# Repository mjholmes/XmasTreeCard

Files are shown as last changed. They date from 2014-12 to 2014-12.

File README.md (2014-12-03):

# XmasTreeCard
#### A geeky Christmas card with LEDs and an OLED display

This circuit and board assembled into a Christmas tree shaped card with 11 LEDs driven by a 12-bit shift register and a small, 0.91", OLED display.

It's a bit rough and needs some more polish when time allows.

This work is licensed under a [Creative Commons Attribution-ShareAlike 4.0 International License](http://creativecommons.org/licenses/by-sa/4.0/).

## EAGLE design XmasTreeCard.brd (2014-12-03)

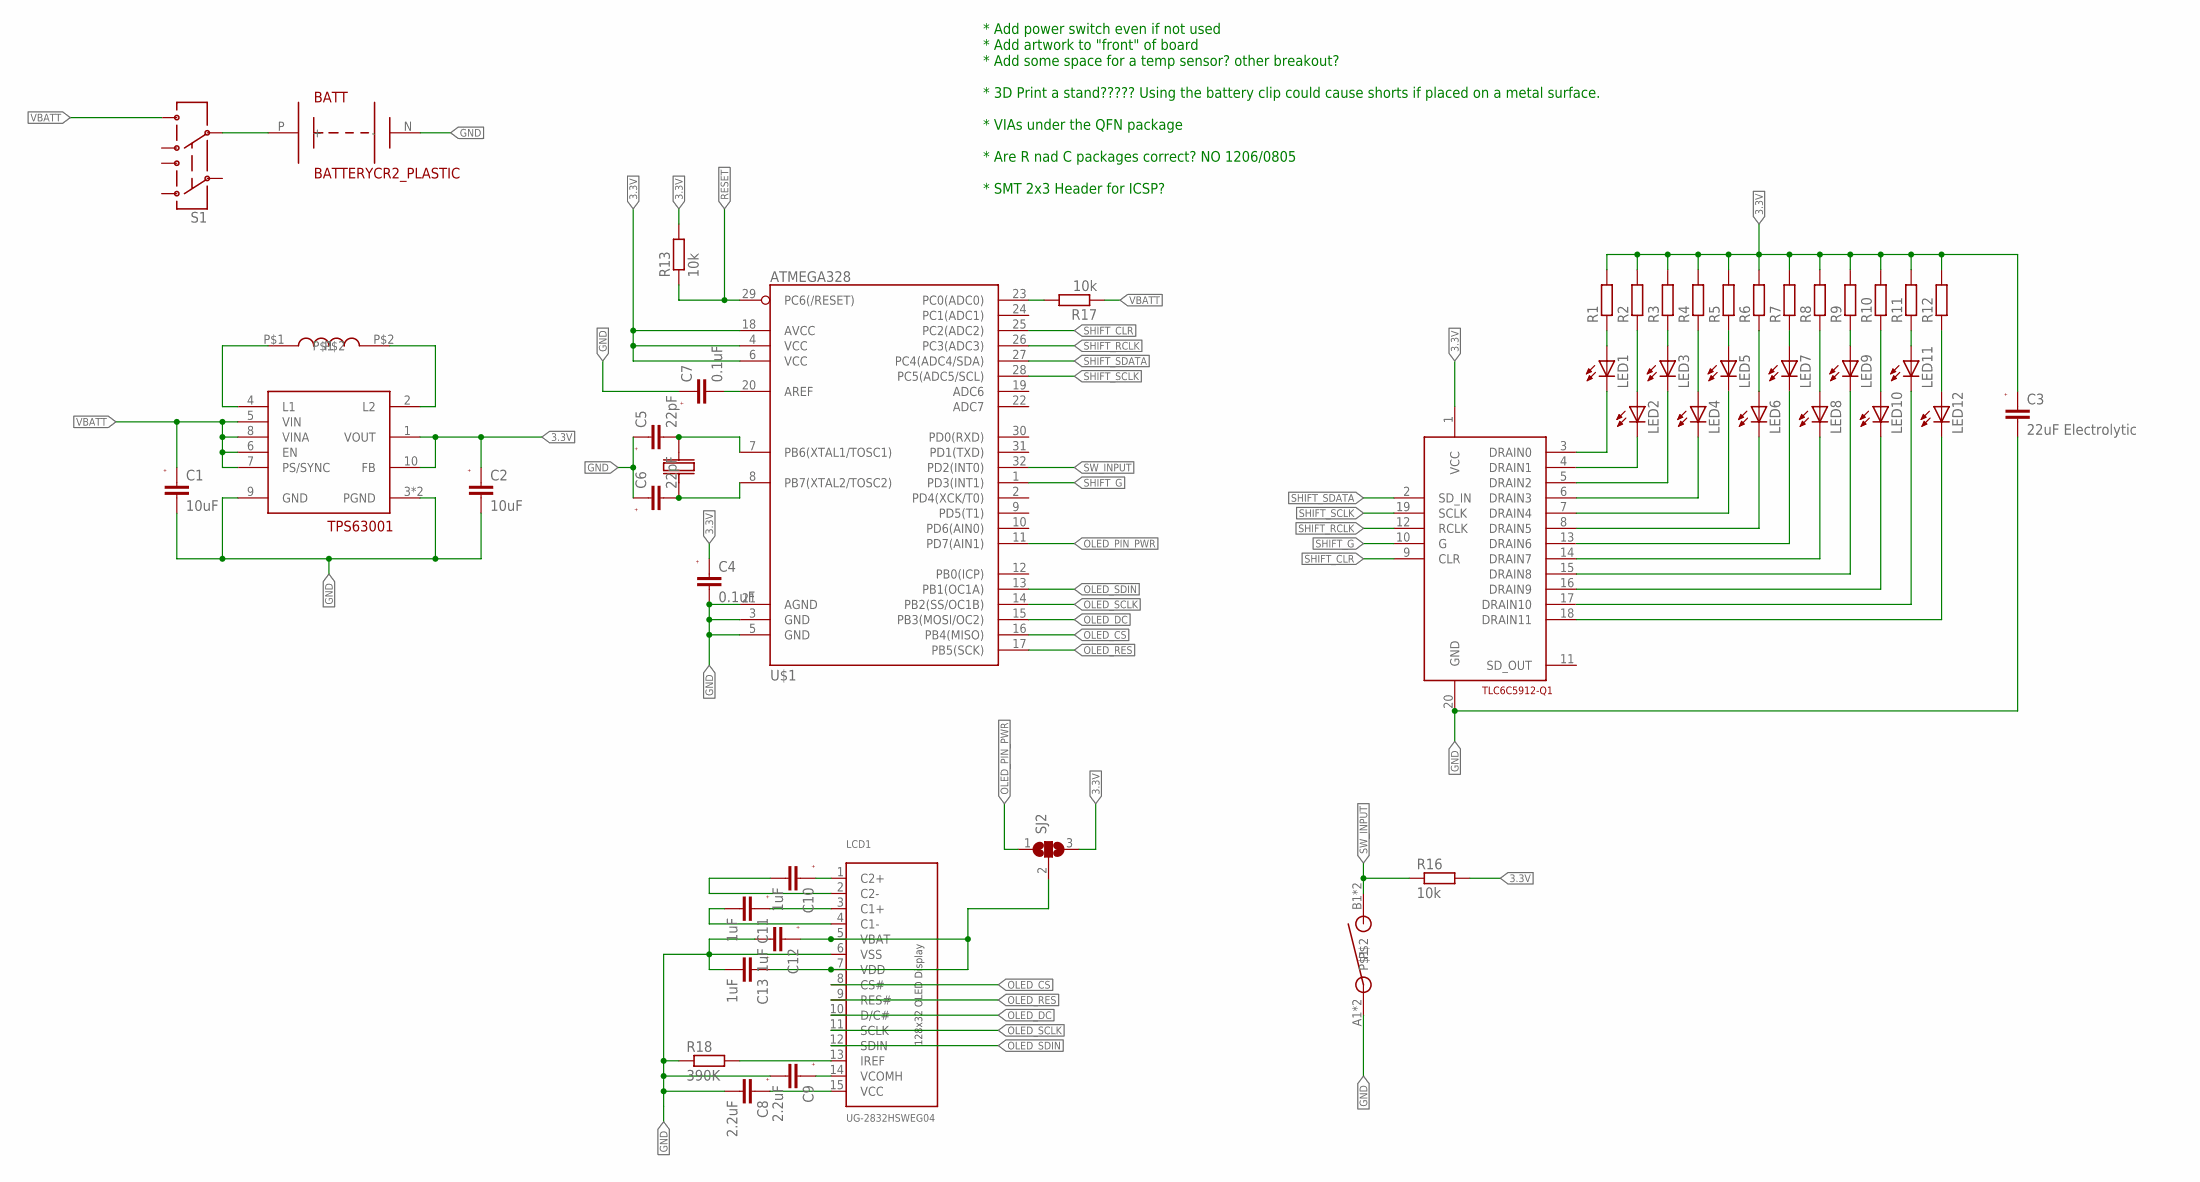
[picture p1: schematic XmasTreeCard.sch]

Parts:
BATT: BATTERYCR2_PLASTIC; BATT_SMD_CR2_PLASTIC
C1, C2: 10uF; C1206
C3: 22uF Electrolytic; CAP_2012-15
C4, C7: 0.1uF; C0805K
C5, C6: 22pF; C0805K
C8, C9: 2.2uF; C1206
C10, C11, C12, C13: 1uF; C1206
LCD1: UG-2832HSWEG04; UG-283HSWEG04_FOLDAROUND
LED1, LED2, LED3, LED4, LED5, LED6, LED7, LED8, LED9, LED10, LED11, LED12: LEDCHIPLED_0805; CHIPLED_0805
R1, R2, R3, R4, R5, R6, R7, R8, R9, R10, R11, R12: R-EUR0805; R0805
R13, R16, R17: 10k; R0805
R18: 390K; R0805
S1: SWITCH-DPDTMMS228; MMS_228_T
SJ2: SJ2W; SJ_2
SW1: SWITCH_SPST6X6TACTILE; SWITCH_SPST_6X6_TACTILE
U$1: ATMEGA328; TQFP32-08
U$2: COILCRAFT_LPS4012
U$3: TPS63001DRC; QFN10_3X3MM
U$4: TLC6C5912-Q1; TSSOP-20
U$5: CRYSTAL_ABM03; ABM_CRYSTAL

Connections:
3.3V: C2.1, C3.P (1), C4.1, R1.2, R2.2, R3.2, R4.2, R5.2, R6.2, R7.2, R8.2, R9.2, R10.2, R11.2, R12.2, R13.2, R16.2, SJ2.3, U$1.4 (VCC), U$1.6 (VCC), U$1.18 (AVCC), U$3.1 (VOUT), U$3.10 (FB), U$4.1 (VCC)
GND: BATT.N (-), C1.2, C2.2, C3.N (2), C4.2, C5.1, C6.1, C7.1, C8.2, C9.2, C12.2, C13.2, LCD1.6 (VSS), R18.1, SW1.A1, SW1.A2, U$1.3 (GND), U$1.5 (GND), U$1.21 (AGND), U$3.3 (PGND), U$3.9 (GND), U$3.11 (PGND), U$4.20 (GND)
unnamed: U$2.P$1, U$3.4 (L1)
unnamed: U$2.P$2, U$3.2 (L2)
unnamed: LED1.A, R1.1
unnamed: LED2.A, R2.1
unnamed: LED3.A, R3.1
unnamed: LED4.A, R4.1
unnamed: LED5.A, R5.1
unnamed: LED6.A, R6.1
unnamed: LED7.A, R7.1
unnamed: LED8.A, R8.1
unnamed: LED9.A, R9.1
unnamed: LED10.A, R10.1
unnamed: LED11.A, R11.1
unnamed: LED12.A, R12.1
unnamed: LED1.C, U$4.3 (DRAIN0)
unnamed: LED2.C, U$4.4 (DRAIN1)
unnamed: LED3.C, U$4.5 (DRAIN2)
unnamed: LED4.C, U$4.6 (DRAIN3)
unnamed: LED5.C, U$4.7 (DRAIN4)
unnamed: LED6.C, U$4.8 (DRAIN5)
unnamed: LED7.C, U$4.13 (DRAIN6)
unnamed: LED8.C, U$4.14 (DRAIN7)
unnamed: LED9.C, U$4.15 (DRAIN8)
unnamed: LED10.C, U$4.16 (DRAIN9)
unnamed: LED11.C, U$4.17 (DRAIN10)
unnamed: LED12.C, U$4.18 (DRAIN11)
unnamed: C5.2, U$1.7 (PB6(XTAL1/TOSC1)), U$5.2
unnamed: BATT.P (+), S1.6 (5)
unnamed: C6.2, U$1.8 (PB7(XTAL2/TOSC2)), U$5.1
unnamed: C7.2, U$1.20 (AREF)
unnamed: R17.2, U$1.23 (PC0(ADC0))
unnamed: C10.2, LCD1.2 (C2-)
unnamed: C10.1, LCD1.1 (C2+)
unnamed: C11.2, LCD1.4 (C1-)
unnamed: C11.1, LCD1.3 (C1+)
unnamed: LCD1.13 (IREF), R18.2
unnamed: C9.1, LCD1.14 (VCOMH)
unnamed: C8.1, LCD1.15 (VCC)
unnamed: C12.1, C13.1, LCD1.5 (VBAT), LCD1.7 (VDD), SJ2.2
OLED_CS: LCD1.8 (CS#), U$1.16 (PB4(MISO))
OLED_DC: LCD1.10 (D/C#), U$1.15 (PB3(MOSI/OC2))
OLED_PIN_PWR: SJ2.1, U$1.11 (PD7(AIN1))
OLED_RES: LCD1.9 (RES#), U$1.17 (PB5(SCK))
OLED_SCLK: LCD1.11 (SCLK), U$1.14 (PB2(SS/OC1B))
OLED_SDIN: LCD1.12 (SDIN), U$1.13 (PB1(OC1A))
RESET: R13.1, U$1.29 (PC6(/RESET))
SHIFT_CLR: U$1.25 (PC2(ADC2)), U$4.9 (CLR)
SHIFT_G: U$1.1 (PD3(INT1)), U$4.10 (G)
SHIFT_RCLK: U$1.26 (PC3(ADC3)), U$4.12 (RCLK)
SHIFT_SCLK: U$1.28 (PC5(ADC5/SCL)), U$4.19 (SCLK)
SHIFT_SDATA: U$1.27 (PC4(ADC4/SDA)), U$4.2 (SD_IN)
SW_INPUT: R16.1, SW1.B1, SW1.B2, U$1.32 (PD2(INT0))
VBATT: C1.1, R17.1, S1.7 (6), U$3.5 (VIN), U$3.6 (EN), U$3.7 (PS/SYNC), U$3.8 (VINA)

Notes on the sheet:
* Add power switch even if not used * Add artwork to "front" of board * Add some space for a temp sensor? other breakout? * 3D Print a stand????? Using the battery clip could cause shorts if placed on a metal surface. * VIAs under the QFN package * Are R nad C packages correct? NO 1206/0805 * SMT 2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

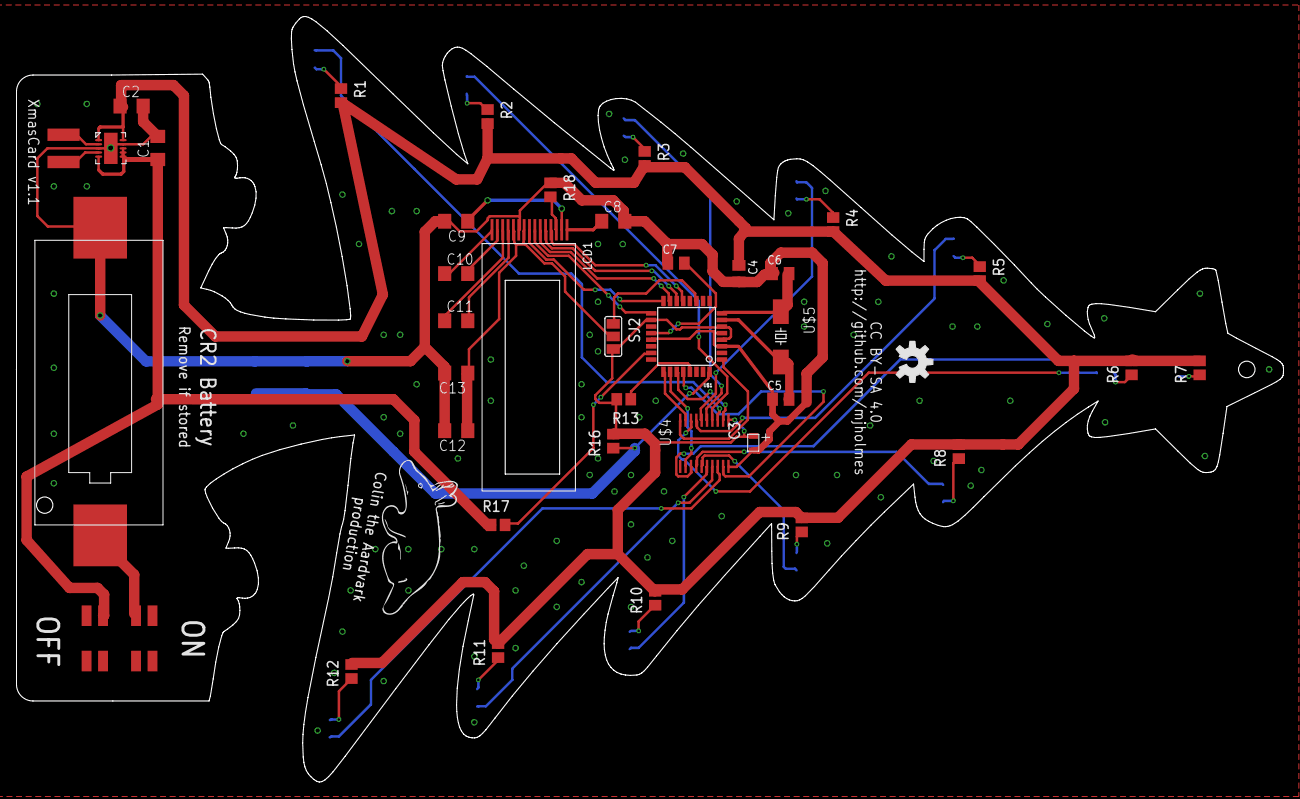
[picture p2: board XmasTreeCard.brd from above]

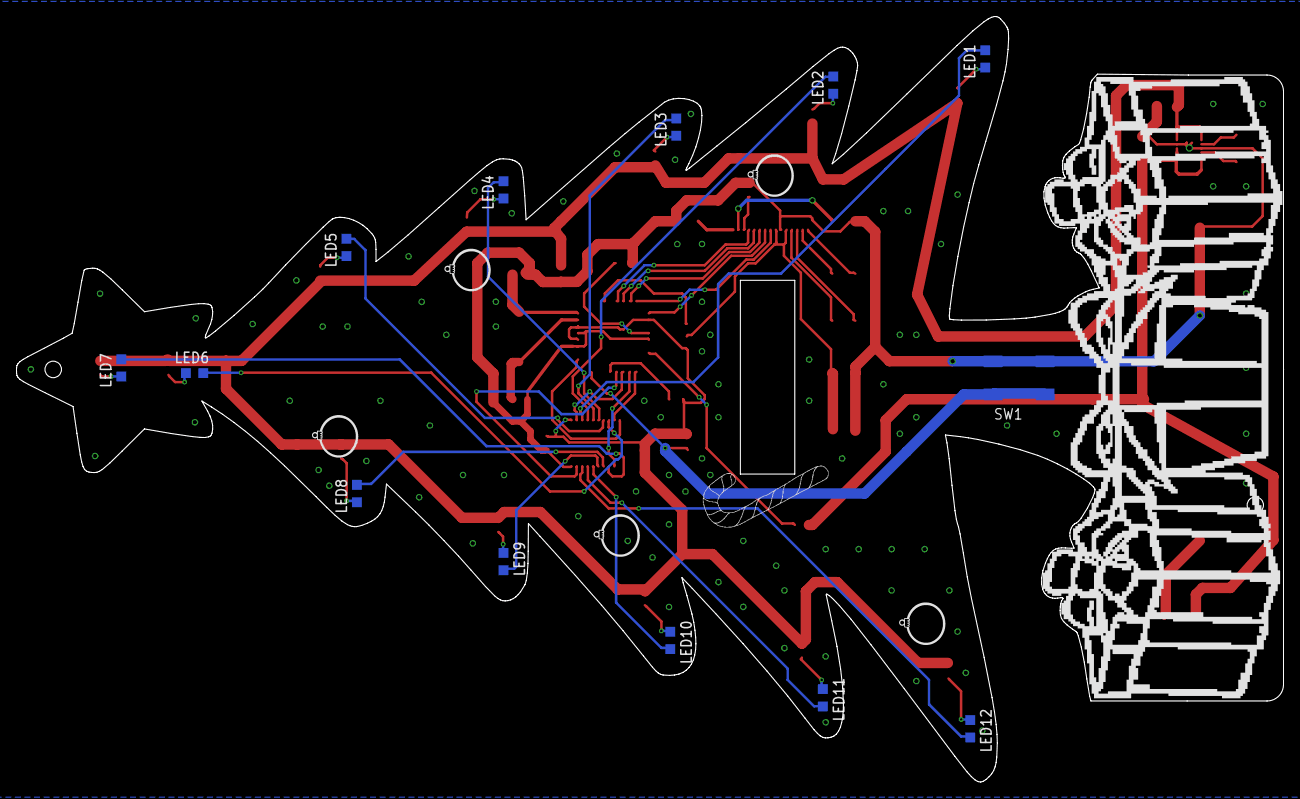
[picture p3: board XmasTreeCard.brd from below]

Board: 2 copper layers, 153.7 x 92.9 mm, 52 parts (13 on the bottom side), 55 nets.

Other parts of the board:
U$6: OSHW-LOGO-M

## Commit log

2014-12-03 Added CC BY-SA 4.0 License
    [XmasTreeCard.brd]
2014-12-03 Added v1 gerbers
    The v1 Gerbers were created before the CC BY-SA 4.0 license details were
    added but can be used under that license.

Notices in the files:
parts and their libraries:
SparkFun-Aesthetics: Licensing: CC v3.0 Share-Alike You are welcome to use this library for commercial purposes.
